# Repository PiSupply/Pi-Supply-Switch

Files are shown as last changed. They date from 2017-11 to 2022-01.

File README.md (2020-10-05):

pisupply-switch-banner
# Pi-Supply-Switch
[Pi Supply Switch On/Off Switch](https://www.pi-supply.com/product/pi-supply-raspberry-pi-power-switch/) for Raspberry Pi

**Remember to install the code before connecting the switch to the Pi.**

## Installation
1. Login via SSH or via the console.
2. Run the following command and Pi Switch will be setup and installed:
```bash
curl -sSL https://pisupp.ly/piswitchcode | sudo bash
```
For OctoPrint run the following:
```bash
curl -sSL https://pisupp.ly/piswitchoctoprint | bash
```

With this new script any standard pin can be chosen to provide the function previously covered by pins 7 and 8.
Within softshut.py you can change the assignment which by default is

```python
PinSeven = 7
PinEight = 11
```

This means that pin 7 coming from the Pi Switch goes to pin 7 on the Raspberry Pi and that pin 8 from the Pi Switch goes to pin 11 on the Raspberry Pi.

```
PiSwitch 7 <---> RPi 7
PiSwitch 8 <---> RPi 11
```

Remember that the notation used is the physical notation only.

**Note that the file to be changed once the installation has been carried out is located under /opt/piswitch/softshut.py and will need to be edited as root**
```bash
sudo nano /opt/piswitch/softshut.py
```

## Usage

* Press the On button to power on the Raspberry Pi.
* Press the Off button to remove power to the Raspberry Pi. This is not a graceful shutdown!
* Press briefly the Soft button to gracefully shutdown the operating system. After 2 minutes the power is also cut off.
* Press the Soft button and keep pressed for a reboot.

# FAQ
## My Pi switches off before fully booting
To avoid this condition always use the Pi Switch in conjunction with the script above. Neither the switch nor the script will work on their own and will result in the powering off of the Raspberry Pi shortly after booting. As previously pointed out you need to install the code before connecting the switch. To remove the switch run the uninstall.sh script before returning to powering the Raspberry Pi only with a traditional PSU.
Should you not have been able to run the uninstall.sh in order to be able to access your OS without it prematurely powering off you can use the following workaround.
Use the jumper cable provided with the switch and connect pin 7 on the Raspberry Pi to pin 9 (GND) and boot normally. This will trick the script into behaving as if the Pi Switch was connected. At this point you can run the uninstall.sh, power off the system and unplug the jumper cable.

## Where can I find an assembly guide?
A [text guide](https://learn.pi-supply.com/make/pi-supply-switch-assembly-instructions/) can be found on our website alternative you can also find a [steb by step video](https://www.youtube.com/watch?v=bHj_pMD7oLI&feature=youtu.be).

## I am still running Wheezy where can I find compatible code?
The [original code for the Pi Switch](https://learn.pi-supply.com/pi-supply-switch-v1-1-code-examples/) can be found on our website.

## Raspbian shows under-voltage warnings
The problem can be solved by using shorter, thicker USB cables. With Pi Switch we are now shipping 30cm 22AWG USB cables which solve the problem entirely.

## How do I know if the service is running properly?
Run the following command
```bash
systemctl status piswitch.service
```
which should return something like
```
● piswitch.service - Starts softshut for Pi Switch
   Loaded: loaded (/etc/systemd/system/piswitch.service; enabled)
   Active: active (running) since Thu 2017-06-29 09:56:13 UTC; 6min ago
 Main PID: 427 (python)
   CGroup: /system.slice/piswitch.service
           └─427 python /opt/piswitch/softshut.py

```

## Open Source Hardware

We are proud to say that the Pi Supply Switch is certified by the [Open Source Hardware Association](https://certification.oshwa.org/uk000019.html) with UID number UK000019. Our certification mark is below:

OSHW_mark_UK000019

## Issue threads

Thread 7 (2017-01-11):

Unexpected shutdown without pressing the button

coconut147, 2017-01-11:
I recognized some unexpected shutdowns with my PiSupply Board.

First I thought it is an hardware issue and started to measure with an oscilloscope but everything looked fine.
I recognized that touching mass the raspberry _can_ invoke the shutdown.

It seems that spikes will produce rising edges on the GPIO.

I already created a proof of concept on my fork at the branch "coconut147_RetroPi"

https://github.com/coconut147/Pi-Supply-Switch/tree/coconut147_RetroPi

If you have a look at commit
https://github.com/coconut147/Pi-Supply-Switch/commit/e24678bb18e51f845d3375cab7b9fa1b2fbed239

you'll find my approach I'm testing right now.

francesco-vannini, 2017-01-11:
Thanks Freddy, that's interesting although a bit disappointing :(
I'll test tomorrow myself and incorporate your changes.

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

--
Francesco Vannini

Website http://garagetech.tips
LinkedIn https://uk.linkedin.com/in/garagetechlinkedin
Youtube https://www.youtube.com/user/Happylotube
Twitter @GarageTechTweet
Facebook https://www.facebook.com/GarageTechBook/
<https://m.facebook.com/GarageTechBook/>
Google+ https://plus.google.com/+FrancescoVannini

shawaj, 2017-01-11:
@coconut147 what do you mean by "touching mass"?

coconut147, 2017-01-11:
I meant touching some point at the board that has connection to ground.

If you have a look at the original example code snippet, there is a debouncing  setting. I assume that this is the reason why it wasn't discovered earlier...
'''
gpio.add_event_detect(7, gpio.RISING, callback=shutdown, bouncetime=200) # Set up an interrupt to look for button presses
 '''

coconut147, 2017-01-11:
Just to clarify:

"Unexpected shutdown": The soft off functionality of the script is invoked, it's not a hard power cut

shawaj, 2017-01-11:
Aha good spot! Thanks

shawaj, 2017-01-11:
If you add deboince back in does it fix the problems?

coconut147, 2017-01-12:
I did not test the debounce setting. But my code is basically doing the same. When an edge is detected, it waits for 100ms. If the button is still pressed, the shutdown is invoked, otherwise ignored.

shawaj, 2017-01-12:
The debounce setting would be a "cleaner" way to do it though surely?

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

coconut147, 2017-01-12:
Please have a look at https://sourceforge.net/p/raspberry-gpio-python/wiki/Inputs/

I think the function "add_event_detect" - that has the debounce parameter - is supposed to be used in games or programs where you don't want to have a blocking call to wait for a "user input".

In the case of the Pi-Supply-Switch we want to have a service that does not use much CPU time. So wait_for_edge() is the way to go in my opinion. The function will suspend the running process until there is an interrupt on the GPIO.

If an edge is detected the program can sleep (thread suspended again) for 100 ms. Afterwards we'll check the actual state if the GPIO. If the button is still pressed we have a confirmed pressed button and can do the shutdown - if the button has been released before we might have seen a spike. In this case we shouldn't do anything and wait for another interrupt of the GPIO.

shawaj, 2017-01-12:
Great explanation and you're right that sounds like the best way

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

coconut147, 2017-01-15:
I created a PR that includes the fix.

francesco-vannini, 2017-01-15:
I understand your points but I believe we should use
"add_event_detect" instead and use a callback function:

def shutdown():
    GPIO.output(PinEight,0)
    call('poweroff', shell=False)

GPIO.add_event_detect(PinSeven, GPIO.RISING, callback=shutdown,
bouncetime=100)

it is more readable and I feel more appropriate, also it doesn't require
the additional time library.
Thoughts?

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

--
Francesco Vannini

<https://twitter.com/GarageTechTweet>
<https://www.youtube.com/user/Happylotube>
<https://uk.linkedin.com/in/garagetechlinkedin>
<https://www.facebook.com/GarageTechBook/>
<https://plus.google.com/+FrancescoVannini>
<http://garagetech.tips/?feed=rss2>  <http://blog.happylot.net/>

coconut147, 2017-01-15:
What will you do to halt execution after registering the callback?
add_event_detect is a non blocking call, so the script needs to do something afterwards.

You might want to halt the execution forever, perhaps with a ```while(True)``` loop - but that eats up 100% CPU load on  a rPI 1 with basically doing nothing.

If you want to tell the application to suspend - you might want to use ```sleep()```
But that also implies you'll have to import the time library...

francesco-vannini, 2017-01-15:
Yes you are right, I was just about to email you again.
At the moment I can't see any other way. I'll test your code and get on
with the PR.

Thanks

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

--
Francesco Vannini

<https://twitter.com/GarageTechTweet>
<https://www.youtube.com/user/Happylotube>
<https://uk.linkedin.com/in/garagetechlinkedin>
<https://www.facebook.com/GarageTechBook/>
<https://plus.google.com/+FrancescoVannini>
<http://garagetech.tips/?feed=rss2>  <http://blog.happylot.net/>

francesco-vannini, 2017-01-15:
Solved in commit #8

Closed 2017-01-15.

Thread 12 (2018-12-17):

Shutdown after a few minutes

martinjungkunz, 2018-12-17:
Hi there,

I have some problem with my Py-Supply On/Off Switch. On and Off work perfectly fine but the soft shutdown does not. That's not much of a problem since my main goal is to cut the power off.

Secondly, the Pi shuts down after a few minutes when used with the Pi-Supply. It's a hard shutdown. I installed the scripts from Github so I think the problem is with the hardware. Have you ever heard of the board acting like that?
Thank you in advance, best
Martin

martinjungkunz, 2018-12-17:
Yes I did and I got the message posted in the your link

shawaj, 2018-12-17:
It sounds like you didn't connect the flying GPIO cable between the switch and the Pi?

martinjungkunz, 2018-12-18:
Actually i did connect it. If I don't, the Pi aborts the boot after a few seconds. In my case it works fine for about 1 to 3 minutes and then suddenly shuts down.

shawaj, 2018-12-18:
It is likely you don't have the software correctly running then or you haven't connected the cable to the correct pin.

That's really the only two things that can cause the issue you're seeing.

martinjungkunz, 2018-12-18:
Hahaha... and just after I wrote my answer I re-read the readme and realized that 8 goes to 11... will try that later

shawaj, 2018-12-18:
Awesome, let us know how you get on

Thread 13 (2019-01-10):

Start up using pins ( from another pi)

bortek, 2019-01-10:
I understand that this can be used to cut the power off but is there a way to start up pi using Pins and not a button? My intention is to use another pay to control "main" pi both cutting power and starting it up (cold reset).

tvoverbeek, 2019-01-10:
Since SW1 can be used to both shut down (and power off) the Pi (long press) and start it up (short press) you should be able to use the unpopulated header J5 which is in parallel to SW1. Provide a short 3.3V pulse to start it up and a long pulse for shutting it down. For timing see the SW1 settings in the GUI/CLI. Check which pin of J5 has the constant 3.3V and connect the other one to an GPIO output of the other Pi.

bortek, 2019-01-18:
Hmm that should probably work. Let me get the board first and test it.

Do I need any resistors between GPIO and pins or can I connect them directly ?

tvoverbeek, 2019-01-18:
The PiJuice already has a 3k9 resistor between the J5 pin and the sw input.
Hence you should be able to connect the GPIO output from the other pi to the J5 pin directly.

bortek, 2019-01-18:
I was planning to use PiSwitch only, without using PiJuice. Is it possible? And if yes then how do I do about 3.9 resistor?

tvoverbeek, 2019-01-18:
@bortek That is something different from what you wrote originally.
I understood that you wanted to use the main Pi + Pijuice combination controlled by a second RPi.
Do you mean main Pi + PiSwitch controlled from a second RPi?
I do not know the PiSwitch details, but after a quick look at the schematic and docs I do not think its possible.

Closed 2019-01-20.

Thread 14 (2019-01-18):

Start and Stop work.  Shutdown does not

matt-benett, 2019-01-18:
Hello, I have 1.1 on a RPi 3 B+.  Latest version of Retropi.  All updated.

Start works - when on Pi Supply LED is on.
Hard Stop works - when off Pi Supply LED is off.

My issues is:
Soft shutdown does nothing on the Pi or the screen output.  The Pi Supply it turns the LED off/on when I press it.  It does not even kill power after 2 minutes.

piswitch service is running.

I am plugged into Pin 7 and 11.

Any ideas please?
thanks

tvoverbeek, 2019-01-19:
@matt-benett Are you using any GPIO based controllers with Retropie?
Looking at https://github.com/RetroPie/RetroPie-Setup/wiki/GPIO-Modules
It seems some of those modules use pins 7 and 11 which will interfere with the piswitch service.

matt-benett, 2019-01-19:
> @matt-benett Are you using any GPIO based controllers with Retropie?
> Looking at https://github.com/RetroPie/RetroPie-Setup/wiki/GPIO-Modules
> It seems some of those modules use pins 7 and 11 which will interfere with the piswitch service.

no, using USB controller

tvoverbeek, 2019-01-19:
@matt-benett Do you have wiringpi installed?
If not install it with `sudo apt-get install wiringpi`.
Then please provide the output of `gpio readall`
The interesting items are the ones for physical pins 7 and 11

matt-benett, 2019-01-19:
Output

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

Image to preserve formatting

tvoverbeek, 2019-01-20:
RPi GPIO pins 7 (BCM 4) and 11 (BCM17) have the correct state and level.
you wrote earlier the piswitch service is running.
What is the output from `systemctl status piswitch.service`?
Double check the connections from Pi-Switch pins 7 and 8 to RPI GPIO pins 7 and 11 respectively.
See the assembly guide (I guess you did this already).
To get a soft shutdown the press the soft button less than 2 seconds (again, I guess you know this).
Note the warning in the assembly guide about Pi3B and 3B+.

matt-benett, 2019-01-21:
ta.

I am looking at the new and old pin images, and they look the same to me.  Am I missing something?

https://i0.wp.com/learn.pi-supply.com/wp-content/uploads/2013/06/Pins-New-Soft.jpg?w=1000&ssl=1

https://i2.wp.com/learn.pi-supply.com/wp-content/uploads/2018/12/20181218_164817.jpg?w=1000&ssl=1

I will check output of `systemctl status piswitch.service` tonight, but I recall it looking all ok.

shawaj, 2019-01-22:
The options as shown in the two pictures here are pins 2 and 6 or pins 7 and 11 - https://learn.pi-supply.com/pi-supply-switch-v1-1-assembly-instructions/

But with the Pin 7 / 11 you need the software running on the pi for it to work correctly

LDDill, 2020-01-31:
Hi I am having the same issue as @matt-benett. The ON and Off buttons work but not the Soft Off button. Show below is what I get when I run "systemctl status piswitch.service". Any suggestions?

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

Thanks

Velocity2018, 2020-02-01:
Did you remember to edit the Python script to change the pin numbers?

LDDill, 2020-02-01:
@Velocity2018 I opened the code to edit it, but it appeared to already be correct.

  GNU nano 2.7.4                            File: /opt/piswitch/softshut.py                               
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

Is there something I need to edit in this file?

Thanks!

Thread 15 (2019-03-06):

Install trying to pull old file version?

Turnwise, 2019-03-06:
Using the command curl -sSL https://pisupp.ly/piswitchcode | sudo bash the install appears to be trying to get the older version of the piswitch code  - deb9u2, when the most recent is d53ff4c I think?

The error is:  Failed to fetch http://mirrordirector.raspbian.org/raspbian/pool/main/g/git/git_2.11.0-3+deb9u2_armhf.deb  404  Not Found [IP: 93.93.128.193 80]

francesco-vannini, 2019-03-07:
Hi @Turnwise , AFAICT the install script uses

`git clone https://github.com/PiSupply/Pi-Supply-Switch.git`

and the URL [https://pisupp.ly/piswitchcode](url) retrives the right version of install.

Could you use a browser and verify that the version of install on the master branch is the same you get?

Even just by running `curl -sSL https://pisupp.ly/piswitchcode`

you should get:

#!/usr/bin/env bash

#Check if script is being run as root
if [ "$(id -u)" != "0" ]; then
   echo "This script must be run as root" 1>&2
   exit 1
fi

if [ ! $? = 0 ]; then
   exit 1
else
   apt-get install -y git whiptail #Installs packages which might be missing

   PiSupplySwitchDir="Pi-Supply-Switch"
   if [ -d "$PiSupplySwitchDir" ]; then
    whiptail --title "Installation aborted" --msgbox "$PiSupplySwitchDir already exists, please remove it and restart the installation" 8 78
    exit
   else
    git clone https://github.com/PiSupply/Pi-Supply-Switch.git
   fi

   mkdir /opt/piswitch

   cp $PiSupplySwitchDir/softshut.py /opt/piswitch
   if [ ! -f /opt/piswitch/softshut.py ]; then
     whiptail --title "Installation aborted" --msgbox "There was a problem writing the softshut.py file" 8 78
    exit
   fi
   cp $PiSupplySwitchDir/piswitch.service /etc/systemd/system
   if [ ! -f /etc/systemd/system/piswitch.service ]; then
    whiptail --title "Installation aborted" --msgbox "There was a problem writing the piswitch.service file" 8 78
    exit
   fi

   systemctl enable /etc/systemd/system/piswitch.service
   whiptail --title "Installation complete" --msgbox "Pi Switch installation complete. The system will power off." 8 78
   poweroff
fi

shawaj, 2019-03-08:
The mirror director URL is something to do with the pi repos.

Perhaps try sudo apt-get update and sudo apt-get upgrade too

Turnwise, 2019-03-09:
Thanks both :)

I'm a bit of a beginner with Pi, and bash scripts etc, so bare with me please - in my day job I'm a PL-SQL developer, but we have a whole department to deal this the more tech side of setting stuff up, etc...

francesco-vannini -  Yes, I tried that and compared the install script that took me to against the code I can see just clicking on the install.sh code.

All seems good until the script reaches the clone bit, then it can't find the version it's looking for - hence the 404 Not Found at that point?  Thanks :)

shawaj - "The mirror director URL is something to do with the pi repos" - that sounds possible - I will try your suggestions - I did think the whiptail bit probably did that, but not sure...   I'll come back on this when I get chance to try it, Thanks :)

For anyone interested - or who cares, here's the putty messages from running curl -sSL https://pisupp.ly/piswitchcode | sudo bash

pi@raspberrypi:~ $ curl -sSL https://pisupp.ly/piswitchcode | sudo bash
Reading package lists... Done
Building dependency tree
Reading state information... Done
whiptail is already the newest version (0.52.19-1).
Suggested packages:
  git-daemon-run | git-daemon-sysvinit git-doc git-el git-email git-gui gitk
  gitweb git-arch git-cvs git-mediawiki git-svn
The following packages will be upgraded:
  git
1 upgraded, 0 newly installed, 0 to remove and 119 not upgraded.
Need to get 3,380 kB of archives.
After this operation, 0 B of additional disk space will be used.
Err:1 http://mirrordirector.raspbian.org/raspbian stretch/main armhf git armhf 1:2.11.0-3+deb9u2
  404  Not Found [IP: 93.93.128.193 80]
E: Failed to fetch http://mirrordirector.raspbian.org/raspbian/pool/main/g/git/git_2.11.0-3+deb9u2_armhf.deb  404  Not Found [IP: 93.93.128.193 80]
E: Unable to fetch some archives, maybe run apt-get update or try with --fix-missing?
Cloning into 'Pi-Supply-Switch'...
cp: cannot stat 'Pi-Supply-Switch/softshut.py': No such file or directory
pi@raspberrypi:~ $

tvoverbeek, 2019-03-09:
The `apt-get install -y git whiptail` command at the beginning of the install script fails.
Probably because your `/etc/apt/sources.list` is out of date. mirrordirector.raspbian.org is not used any more.
Try to replace /etc/apt/sources.list with the following:
```
deb http://raspbian.raspberrypi.org/raspbian/ stretch main contrib non-free rpi
# Uncomment line below then 'apt-get update' to enable 'apt-get source'
#deb-src http://raspbian.raspberrypi.org/raspbian/ stretch main contrib non-free rpi
```
You need to edit /etc/apt/sources.list as root (using sudo).
Then run `sudo apt-get update` and `sudo apt-get dist-upgrade` to be sure you are up-to-date.
Then try the install again.

francesco-vannini, 2019-03-10:
Out of curiosity @Turnwise how did you download your Raspbian version? is this a new installation or you are adding the Pi Supply Switch to an existing project which you had been sitting there for a while?

Turnwise, 2019-03-10:
Not sure exact date - but probably around a year or so ago - the on/off switch is to attach to my Pi that is running BrewPi for me (to control temperature in a fermentation cupboard). When it's running, it's out in my shed, only connected to an arduino board that's controlling a relay board - but no screen, or keyboard connected - and I've never managed to connect to the Pi remotely to shut it down gracefully, and 9 times out of 10 it corrupts if I just switch it off, which isn't a disaster as I have a saved image I just drop back on the SD card and off we go again, but it is a bit of a pain, especially as we are out in the sticks and power cuts are more frequent than I'd like, and although usually intermittent, also tend to mean a re-install of the image....

francesco-vannini, 2019-03-11:
@Turnwise I'd follow @tvoverbeek advice and update the OS one way or another. Good luck and let us know how that goes.

Turnwise, 2019-03-17:
Thanks all :)

I've followed @tvoverbeek 's advice :)

I edited the sources list by navigating to it on Putty using the cd command and then edited using vi :
sudo vi sources.list
x to delete characters, i to insert - hit esc once finished inserting
the :wq to exit and save

I then ran the two updates recommended - both did a lot of work! However the dist-upgrade hit an error towards the end :

Preparing to unpack .../libapt-pkg5.0_1.4.9_armhf.deb ...
Unpacking libapt-pkg5.0:armhf (1.4.9) over (1.4.7) ...
dpkg-deb (subprocess): decompressing archive member: lzma error: compressed data is corrupt
dpkg-deb: error: subprocess <decompress> returned error exit status 2
dpkg: error processing archive /var/cache/apt/archives/libapt-pkg5.0_1.4.9_armhf.deb (--unpack):
 cannot copy extracted data for './usr/lib/arm-linux-gnueabihf/libapt-pkg.so.5.0.1' to '/usr/lib/arm-linux-gnueabihf/libapt-pkg.so.5.0.1.dpkg-new': unexpected end of file or stream
Errors were encountered while processing:
 /var/cache/apt/archives/libapt-pkg5.0_1.4.9_armhf.deb
E: Sub-process /usr/bin/dpkg returned an error code (1)

I ran the get update script again - it found nothing new to do, and then the upgrade again, but I got the same 'compressed data is corrupt'

The curl -sSL https://pisupp.ly/piswitchcode | sudo bash now appears to do nothing at all, the cursor just moves to a new line and no action appears to be taken.

Stepping through the individual items in the install script and running individually using sudo, I get as far as  cp $PiSupplySwitchDir/softshut.py /opt/piswitch  - and there I encounter : cp: cannot stat 'Pi-Supply-Switch/softshut.py': No such file or directory

My Mrs has run out of patience waiting for me to finish mucking about with this tonight, so I'm gonna shut it down and come back to it another night!!

Thanks all for your continued patience and support!!!

tvoverbeek, 2019-03-17:
@Turnwise Smells like you SD card is full, so adding anything new fails.
What does `df -h` say? Should show the space available on the different file systems.
I suspect / is full.

Turnwise, 2019-03-24:
Slightly over half full??

Filesystem      Size  Used Avail Use% Mounted on
/dev/root        29G  5.4G   22G  20% /
devtmpfs        458M     0  458M   0% /dev
tmpfs           462M     0  462M   0% /dev/shm
tmpfs           462M   12M  450M   3% /run
tmpfs           5.0M  4.0K  5.0M   1% /run/lock
tmpfs           462M     0  462M   0% /sys/fs/cgroup
/dev/mmcblk0p6   68M   21M   47M  31% /boot
tmpfs            93M     0   93M   0% /run/user/1000

tvoverbeek, 2019-03-25:
Ok, sd card is obviously not full. I seems you have installed Raspbian using NOOBS.
I guess somehow your os installation is messed up.
The only thing I can suggest is to start from scratch and install Raspbian directly using one of the images on the downloads page: https://www.raspberrypi.org/downloads/raspbian/
and then after the initial update/upgrade install the piswitch code.

Turnwise, 2019-03-25:
I've ordered a new SD, and have downloaded the Raspbian Stretch with desktop, without NOOBS. I'll then see how that works!  I'll be a week or so - the Pi was needed back for the BrewPi and is running with the old, but working image that has the BrewPi code and settings, but not the new switch.... fingers crossed there's no power cuts!

tvoverbeek, 2019-03-26:
@Turnwise Let us know how it goes.

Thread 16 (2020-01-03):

Use GPIO14 instead?

opjose, 2020-01-03:
I found this comment on another forum about GPIO.
---
"The one exception might be your pin 15, which looks like it must be GPIO14. However, this pin isn't a GPIO at startup - it's TxD, the serial transmit line - which may well be pulled high for normal TX operation. The TxD line won't become GPIO14 (and therefore go low) until you run your script that enables all 17 lines as GPIOs."

"As I learned from the forums, I use an LED hooked up to GPIO14 and mounted on my chassis to notify me when the pi has completely shut down (The LED is lit at boot and is turned off at shutdown after the files systems have been unmounted."
---

That being the case wouldn't it be better to use the GPIO14 (TxD) pin which appears to remain high during boot, then initialize it in the script as a GPIO line and immediately pull it high in the script?

That way if the user is NOT running the script but has connected the board to GPIO14, they will not experience shutdowns during or after the boot sequence...

Would that work?

Thanks.

shawaj, 2020-01-04:
Yes you can do this no problem.

See here https://github.com/PiSupply/Pi-Supply-Switch/blob/master/README.md#installation

Just change the line PinEight = 11 to PinEight = 8

Closed 2020-01-04.

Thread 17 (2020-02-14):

Softshut Not working

LDDill, 2020-02-14:
Hi I followed all of the instructions step-by-step. I am using a raspberry pi 3B+ running raspbian stretch. The ON and Off buttons work, but not the Softshut Off button. Shown below is what I get when I run "systemctl status piswitch.service". Any suggestions?

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

This is what my softshut.py file looks like.

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

Thanks!

shawaj, 2020-02-14:
Do you have the board hooked up to the Pi as per the guide linked below?

The options as shown in the two pictures here are pins 2 and 6 or pins 7 and 11 - https://learn.pi-supply.com/pi-supply-switch-v1-1-assembly-instructions/

But with the Pin 7 / 11 you need the software running on the pi for it to work correctly

LDDill, 2020-02-14:
Hi @shawaj thanks for reaching out. I have physically hooked up the power switch to my Pi in this order: USB to micro USB from power supply to power switch, USB to micro USB from power switch to Pi, Pin 7 on the power switch to Pin 7 on the Pi, and Pin 8 on the power switch to Pin 11 on the Pi. Because of the error I get when running "systemctl status piswitch.service", I believe my issue is with the software. The error is listed below:

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

Any suggestions?

Thanks!

LDDill, 2020-02-24:
I have found a solution to the error I was receiving, "RuntimeError: Error waiting for edge". There appears to be an issue in the RPi.GPIO directory when calling "GPIO.wait_for_edge(PinSeven, GPIO.RISING)". The code runs perfectly if that line is removed (as shown below).

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

shawaj, 2020-02-25:
@LDDill is this an error in our code? Or something you added?

LDDill, 2020-02-26:
@shawaj The original code had "GPIO.wait_for_edge(PinSeven, GPIO.RISING)" on line 17. However, the code would give an error when ran. After removing that line the code works correctly. With a press initiating shut down and a hold initiating reboot.

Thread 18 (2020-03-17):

Link for the text-guide not working

boschie, 2020-03-17:
Hello,

Is it possible to get all the related files, guides and programs in this repository? It would be more handy and links seems to disappear over time.

Hendrie

ChristopherRush, 2020-03-17:
@boschie Here you go - https://learn.pi-supply.com/make/pi-supply-switch-assembly-instructions/

boschie, 2020-03-17:
@ChristopherRush Thanks!

The link in the README.md is still wrong. Could this page be implemented in the wiki of this repository? Just to keep it all in one place...

ChristopherRush, 2020-03-17:
I'll update the link through Github but at the moment we will not use
Githib wiki since we don't want too many duplication of the same thing.

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

boschie, 2020-03-17:
Ok, thanks!

Closed 2020-03-17.

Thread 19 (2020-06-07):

There was a problem writing the softshut.py file Installation aborted

magellan-13016, 2020-06-07:
Hello,

I have an issue with the script installation.

I run the command

**_curl -sSL https://pisupp.ly/piswitchcode | sudo bash_**

and get the error

**_There was a problem writing the softshut.py file Installation aborted_**

I run this on my octoprint printer server on a raspberry Pi 3B +

Can someone help me please ?
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

shawaj, 2020-06-07:
@ChristopherRush do you have an octoprint setup you can test this with?

ryanteck, 2020-06-07:
Just quickly ran it, seems the issue is with the git clone as it fails due to recommending you don't run git as sudo which as the entire script is sudo'd then fails.

Here's the error log

```pi@octopi:~ $ curl -sSL https://pisupp.ly/piswitchcode | sudo bash
[sudo] password for pi:
Reading package lists... Done
Building dependency tree
Reading state information... Done
git is already the newest version (1:2.20.1-2+deb10u1).
whiptail is already the newest version (0.52.20-8).
whiptail set to manually installed.
The following package was automatically installed and is no longer required:
  libllvm8
Use 'apt autoremove' to remove it.
0 upgraded, 0 newly installed, 0 to remove and 0 not upgraded.
Please do not run git as root, your regular user account is enough :)

If you need to run git with root rights for some other application than
what comes preinstalled on this image you can remove this sanity check:

    sudo rm /root/bin/git

You might have to restart your login session after doing that.
cp: cannot stat 'Pi-Supply-Switch/softshut.py': No such file or directory```

Solution is likely modifying it to download the files directly maybe, or not running the entire script as root?

shawaj, 2020-06-07:
@ryanteck maybe just run the bite that need it as root is easiest?

magellan-13016, 2020-06-08:
To Aaron, Ryan and Christopher : Many thanks for your help. 3 persons to help me I would never expect that ! Now I'm sure one of you will find the solution. Many thanks to you !

ChristopherRush, 2020-06-08:
@ryanteck Did you test it on your OctoPrint? Script runs fine on Raspbian.

ryanteck, 2020-06-08:
Yeah that was on footprint.

On Mon, 8 Jun 2020, 10:17 Christopher Rush, <notifications@github.com>
wrote:

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

ChristopherRush, 2020-06-08:
@ryanteck @shawaj Aarons method seems to work. Run the script as normal user and add root to parts that require it.

magellan-13016, 2020-06-08:
Well... If I run the script as normal user, a message tell me it must be run with root privileges. The best way for me is a new script working for Octoprint.

ChristopherRush, 2020-06-08:
@magellan-13016 Try the following `curl -sSL https://pisupp.ly/piswitchoctoprint | bash`

magellan-13016, 2020-06-08:
Dear team, you're simply the best !

Install is now complete. I suggest you to add this script on the main page of Pi Supply Switch so evey people using Octoprint can install it without any issue.

Many many many thanks to all of you.

David.
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

ivanolenichev, 2020-06-08:
Hi Aaron, @shawaj . Sorry for the off topic post. I can’t contact you by mail or other channels. Please write how you can be contacted?

ChristopherRush, 2020-06-08:
@magellan-13016 Super, I have added it to the main readme section for OctoPrint.

Closed 2020-06-08.

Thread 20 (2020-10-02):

Open source hardware certification

shawaj, 2020-10-02:
Pi Supply Switch certification
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
[OSHW_mark_UK000019.pdf](https://github.com/PiSupply/Pi-Supply-Switch/files/5320742/OSHW_mark_UK000019.pdf)

ChristopherRush, 2020-10-05:
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

ryanteck, 2020-10-05:
Can I just ask why we keep uploading images as issues rather than putting them in the repositories.

Shouldn't they be uploaded to the repo?

shawaj, 2020-10-06:
@ryanteck main idea was to keep the repos tidy and uncluttered and then just link to the images

Closed 2020-10-02.

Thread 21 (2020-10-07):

Softshut reboots after a while

JLGBJ, 2020-10-07:
I have a raspberry pi 3B+, it was running ok both ON and OFF buttons were working perfect. A couple of weeks ago the OFF button started to reboot itself after approximately 3 min., it does a soft shutdown and after 3 min. reboot the PI, when pressed as second time is does a soft shutdown and stays shutdown, could it be a corrupt file? ,  I’m running Octopi.

shawaj, 2020-10-07:
Just to check do you have the 2 pin cable connected between the pi and the switch? If so which pins are you using on the pi and the corresponding pin on the switch?

Can you also post the script you are using? Did you just use the default install method shown in the readme or something else?

Did you make any updates or changes to the software or octopi at all recently?

JLGBJ, 2020-10-12:
Hi @shawaj, thanks for replaying, yes I have the 2 pin cable connected as per the instructions:

PiSwitch 7 <---> RPi 7
PiSwitch 8 <---> RPi 11

The script is softshut.py and it was installed as per de readme file , this is what it looks like:

#!/usr/bin/env python
# Import the modules to send commands to the system and access GPIO pins
from subprocess import call
import RPi.GPIO as GPIO
from time import sleep
# Map pin seven and eight on the Pi Switch PCB to chosen pins on the Raspberry Pi header
# The PCB numbering is a legacy with the original design of the board
PinSeven = 7
PinEight = 11
GPIO.setmode(GPIO.BOARD) # Set pin numbering to board numbering
GPIO.setup(PinSeven, GPIO.IN) # Set up PinSeven as an input
GPIO.setup(PinEight, GPIO.OUT, initial=1) # Setup PinEight as output
while (GPIO.input(PinSeven) == False): # While button not pressed
 GPIO.wait_for_edge(PinSeven, GPIO.RISING) # Wait for a rising edge on PinSeven
 sleep(0.1); # Sleep 100ms to avoid triggering a shutdown when a spike occured
sleep(2); # Sleep 2s to distinguish a long press from a short press
if (GPIO.input(PinSeven) == False):
 GPIO.output(PinEight,0) # Bring down PinEight so that the capacitor can discharge and remove power to the Pi
 call('poweroff', shell=False) # Initiate OS Poweroff
else:
 call('reboot', shell=False) # Initiate OS Reboot

No changes were made to the software or octopi. I´m running Octoprint V.1.4.2 and
Octopi V.0.17.0

JLGBJ, 2020-10-12:
Hi @shawaj, thanks for replaying, yes I have the 2 pin cable connected as per the instructions:

PiSwitch 7 <---> RPi 7
PiSwitch 8 <---> RPi 11

The script is softshut.py and it was installed as per de readme file , this is what it looks like:

#!/usr/bin/env python
#Import the modules to send commands to the system and access GPIO pins
from subprocess import call
import RPi.GPIO as GPIO
from time import sleep
#Map pin seven and eight on the Pi Switch PCB to chosen pins on the Raspberry Pi header
#The PCB numbering is a legacy with the original design of the board
PinSeven = 7
PinEight = 11
GPIO.setmode(GPIO.BOARD) # Set pin numbering to board numbering
GPIO.setup(PinSeven, GPIO.IN) # Set up PinSeven as an input
GPIO.setup(PinEight, GPIO.OUT, initial=1) # Setup PinEight as output
while (GPIO.input(PinSeven) == False): # While button not pressed
 GPIO.wait_for_edge(PinSeven, GPIO.RISING) # Wait for a rising edge on PinSeven
 sleep(0.1); # Sleep 100ms to avoid triggering a shutdown when a spike occured
sleep(2); # Sleep 2s to distinguish a long press from a short press
if (GPIO.input(PinSeven) == False):
 GPIO.output(PinEight,0) # Bring down PinEight so that the capacitor can discharge and remove power to the Pi
 call('poweroff', shell=False) # Initiate OS Poweroff
else:
 call('reboot', shell=False) # Initiate OS Reboot

No changes were made to the software or octopi. I´m running Octoprint V.1.4.2 and Octopi V.0.17.0

Thanks

JLGBJ, 2020-10-18:
@shawaj  Any suggestions

Thanks

shawaj, 2020-10-18:
@JLGBJ when you run the script directly, do you get any error messages at all?

JLGBJ, 2020-10-18:
@shawaj Thanks for your replay, No I don’t get any error, I get this when I check the status:
pi@octopi:~ $ systemctl status piswitch.service
● piswitch.service - Starts softshut for Pi Switch
   Loaded: loaded (/etc/systemd/system/piswitch.service; enabled; vendor preset: enabled)
   Active: active (running) since Mon 2020-10-12 11:55:26 BST; 6 days ago
 Main PID: 301 (python)
    Tasks: 1 (limit: 2077)
   Memory: 5.2M
   CGroup: /system.slice/piswitch.service
           └─301 python /opt/piswitch/softshut.py

Oct 12 11:55:26 octopi systemd[1]: Started Starts softshut for Pi Switch.

Could it be the Pi Switch it self and not the software?

Thanks

JLGBJ, 2020-10-18:
how do you run it directly?

El dom., 18 oct. 2020 a las 15:09, Aaron Shaw (<notifications@github.com>)
escribió:

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

JLGBJ, 2020-10-19:
@shawaj , sorted, I changed the Pi-Switch for another unit I had and it is working perfectly. Do you have any suggestions as to what component could be faulty, to see if I can repaired it?. Thanks for your help

shawaj, 2020-10-19:
It could be the relay perhaps isn't switching correctly

shawaj, 2020-10-19:
@JLGBJ can you send me an email to sales@pi-supply.com - I think we might have some spare in the warehouse. I could send you one :-)

Closed 2020-10-19.

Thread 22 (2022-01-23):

power off after two minutes

naturenergy, 2022-01-23:
Hello!

I have an issue where the Pi (Arm 6 Model A rev2) using Dietpi 8.02 OS which I understand is based on Bullseye Debian.

Powers off after about 2 minutes (sudden off no gentle shutdown - so risk of card corruption).

I installed the code and switch as per instructions and it has worked fine previously on raspberry OS lite (headless)

Keen to use DietPi however, and like its functionality.

I used the default pins 7 and 11, and tried again changing to pins 11,15 (editing the script) same result. Also tried changing the power lead and have a good 2A supply which is ample for model A.

Ran the service status diagnostic (with switch attached) :-

● piswitch.service - Starts softshut for Pi Switch
     Loaded: loaded (/etc/systemd/system/piswitch.service; enabled; vendor preset: enabled)
     Active: failed (Result: exit-code) since Sun 2022-01-23 09:32:20 GMT; 3min 34s ago
    Process: 182 ExecStart=/opt/piswitch/softshut.py (code=exited, status=127)
   Main PID: 182 (code=exited, status=127)
        CPU: 33ms

Jan 23 09:32:19 RPi1PV systemd[1]: Started Starts softshut for Pi Switch.
Jan 23 09:32:20 RPi1PV softshut.py[182]: /usr/bin/env: ‘python’: No such file or directory
Jan 23 09:32:20 RPi1PV systemd[1]: piswitch.service: Main process exited, code=exited, status=127/n/a
Jan 23 09:32:20 RPi1PV systemd[1]: piswitch.service: Failed with result 'exit-code'.

Then I tested it without the switch and the OS remains stable and on for a long time.

Looking at above - perhaps python hasn't been installed correctly by default in Dietpi? Any ideas? Thanks!

tvoverbeek, 2022-01-23:
I have no experience with DietPi, but from your status output it is obvious that the 'python' command is not defined.
In a terminal window (with switch not attached) try to run the command `python` which will most likely fail.
I guess only python3 is installed. To check this, try to run the command `python3` in the terminal window.
If that works change the first line in softshut.py to `/usr/bin/env python3`.
If that does not work you will have to install python (preferably python3, since python2 is not maintained any more).

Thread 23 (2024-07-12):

Error: No module named 'RPi' - RPI shuts down after 30sec

silas-vj, 2024-07-12:
Hi there,

I hope I can get this issue fixed, because my system worked completely fine before but after a crash I had to do a fresh install on my RPI 3 B+ and now after I press the ON Button the RPI shuts down after approx. 30sec during boot, because the relay cuts off power. I cannot make the system boot normally.

I hooked it up to a second power supply, booted and entered "systemctl status piswitch.service" via ssh.

I am getting the following Response message (see also picture attached below):

● piswitch.service - Starts softshut for Pi Switch
    Loaded: loaded (/etc/systemd/system/piswitch.service; enabled; vendor preset: enabled)
   Active: failed (Result: exit-code) since Fri 2024-07-12 19:14:57 CEST; 38min ago
   Main PID: 616 (code=exited, status=1/FAILURE)

Jul 12 19:14:53 np-one systemd[1]: Started Starts softshut for Pi Switch.
Jul 12 19:14:57 np-one softshut.py[616]: Traceback (most recent call last):
Jul 12 19:14:57 np-one softshut.py[616]:   File "/opt/piswitch/softshut.py", line 5, in <module>
Jul 12 19:14:57 np-one softshut.py[616]:     import RPi.GPIO as GPIO
Jul 12 19:14:57 np-one softshut.py[616]: ModuleNotFoundError: No module named 'RPi'
Jul 12 19:14:57 np-one systemd[1]: piswitch.service: Main process exited, code=exited, status=1/FAILURE
Jul 12 19:14:57 np-one systemd[1]: piswitch.service: Failed with result 'exit-code'.

Thank You!

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

silas-vj, 2024-10-07:
Instructions explained in following volumio community thread:
[https://community.volumio.com/t/pi-supply-switch-v1-1-working-with-volumio-v2-246/6730](url)

Closed 2024-10-07.

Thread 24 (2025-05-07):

software does not install

mindstorm2099, 2025-05-07:
I am busy with making a NAS from my raspberry Pi 4 following the guide from https://wiki.omv-extras.org/doku.php?id=omv7:raspberry_pi_install.
But when i try the commabd: "curl -sSL https://pisupp.ly/piswitchcode | sudo bash"
i get the following error: "bash: line 1: error: command not found".
It doesn't matter if i try before installing openmediavault or after.
i know nothing about programming or stuff like that, so i need some help.

lbussy, 2025-05-07:
I am not the author, but maybe this will help.

The domain pisupp.ly (as well as pi-supply.com) is not there, so the short form of the URL is likewise unreachable.  MAYBE this is the right script:

https://github.com/PiSupply/Pi-Supply-Switch/blob/master/install.sh

So the replacement command would be:

```bash
curl -sSL https://raw.githubusercontent.com/PiSupply/Pi-Supply-Switch/refs/heads/master/install.sh | sudo bash
```

Good luck.

mindstorm2099, 2025-05-10:
Thank you.

With this command it works now. got a fully working NAS now.

P.S. i did needed to do a compleet reinstall, installing PiSupply after Openmediavault gives an error.
So a clean install of the OS then PiSupply and the OMV and it works.

Thank you again

Closed 2025-05-10.

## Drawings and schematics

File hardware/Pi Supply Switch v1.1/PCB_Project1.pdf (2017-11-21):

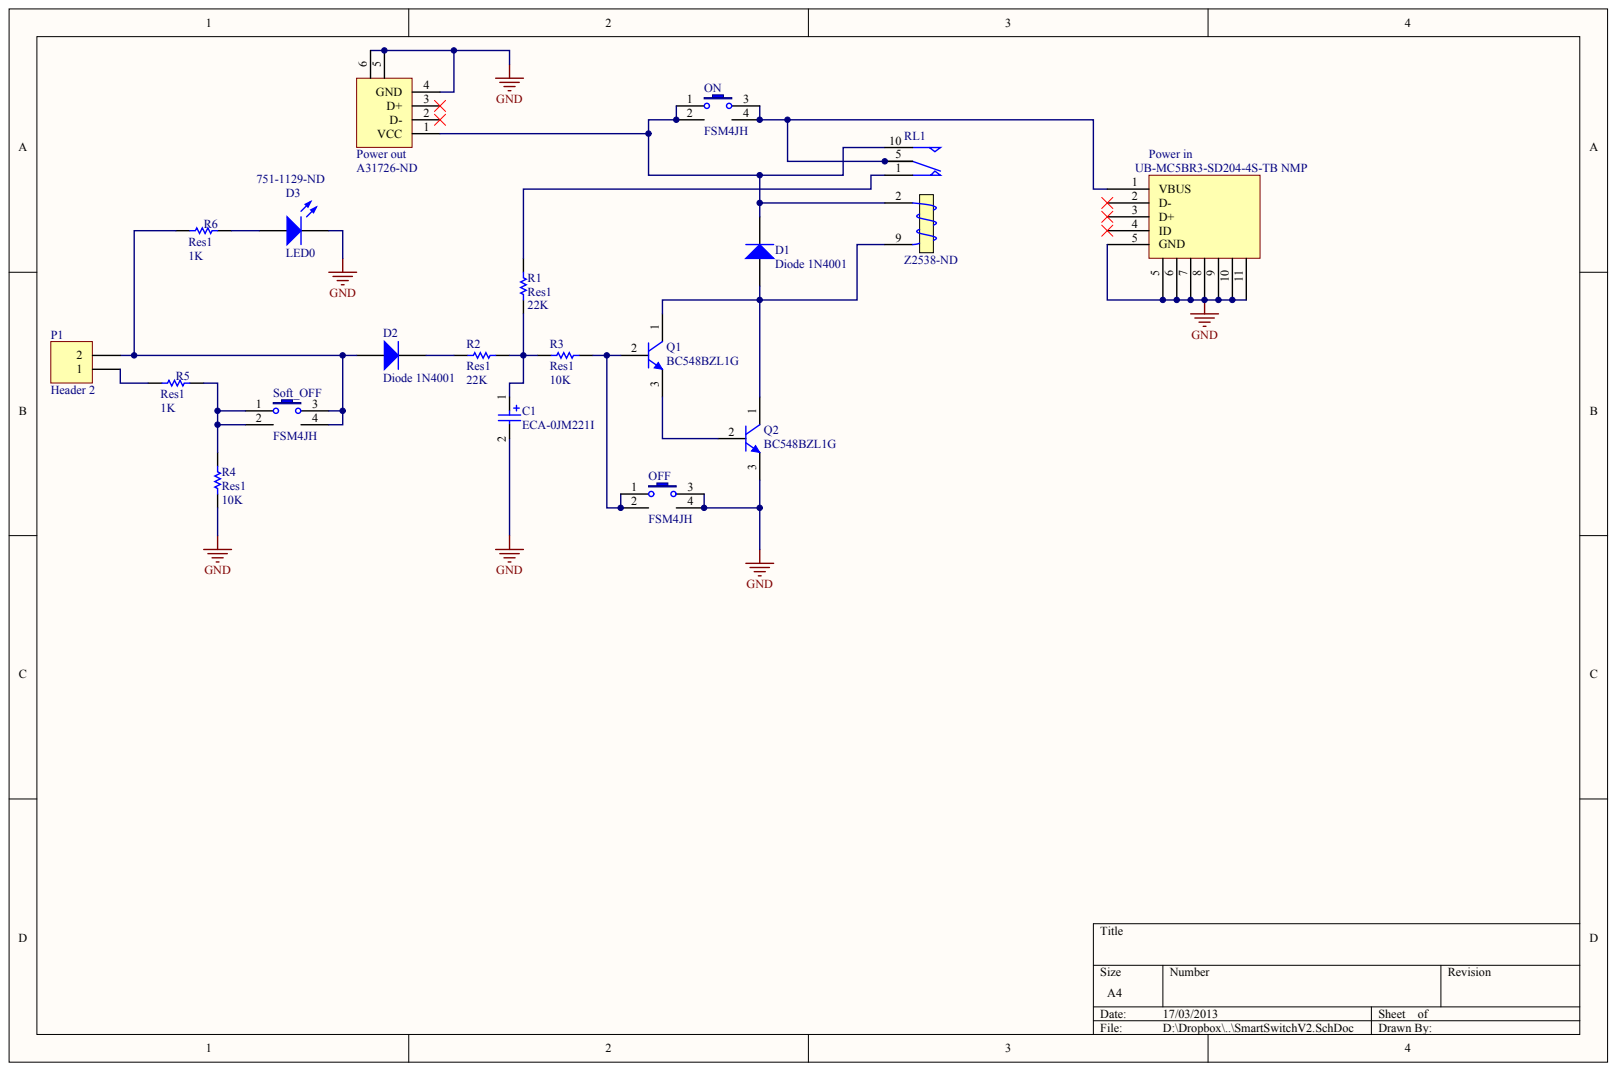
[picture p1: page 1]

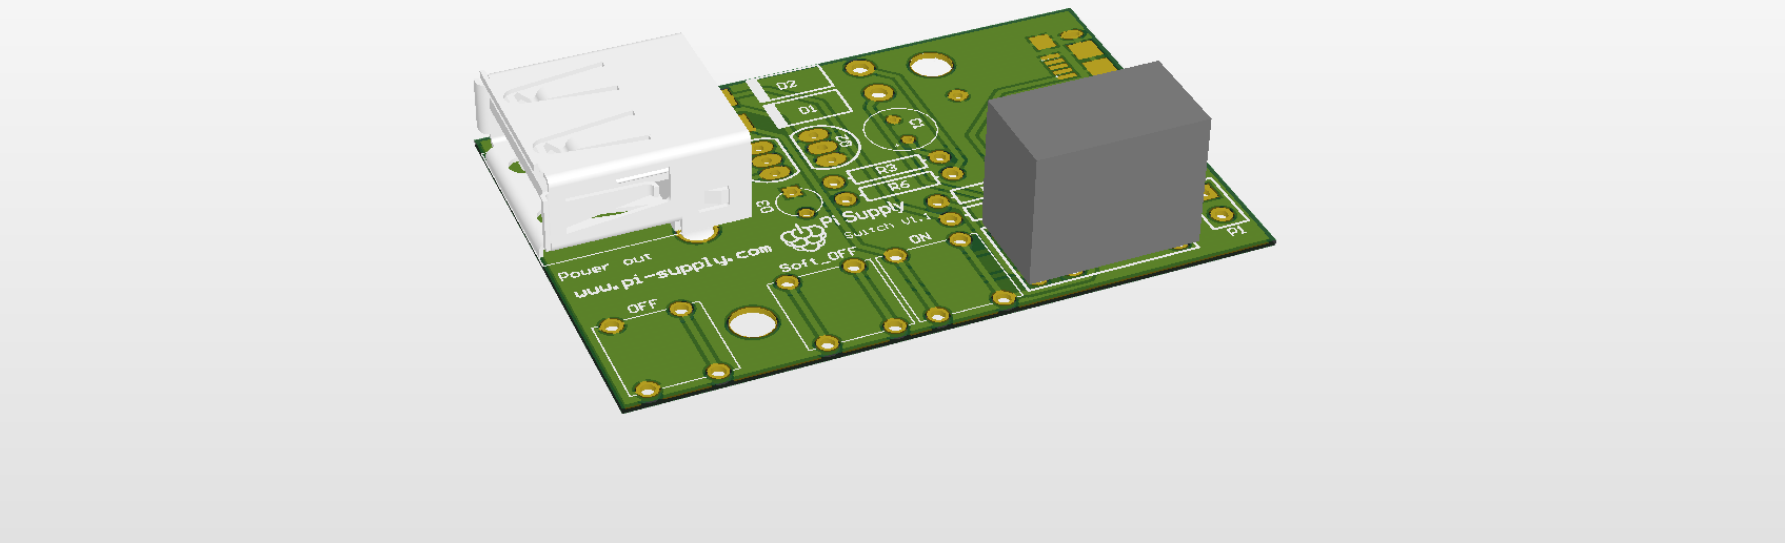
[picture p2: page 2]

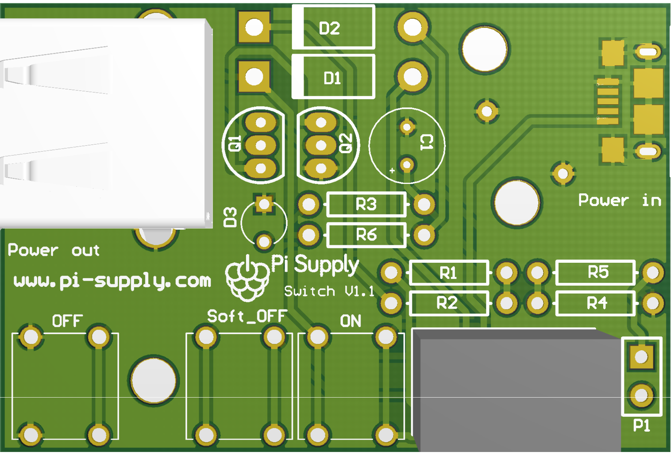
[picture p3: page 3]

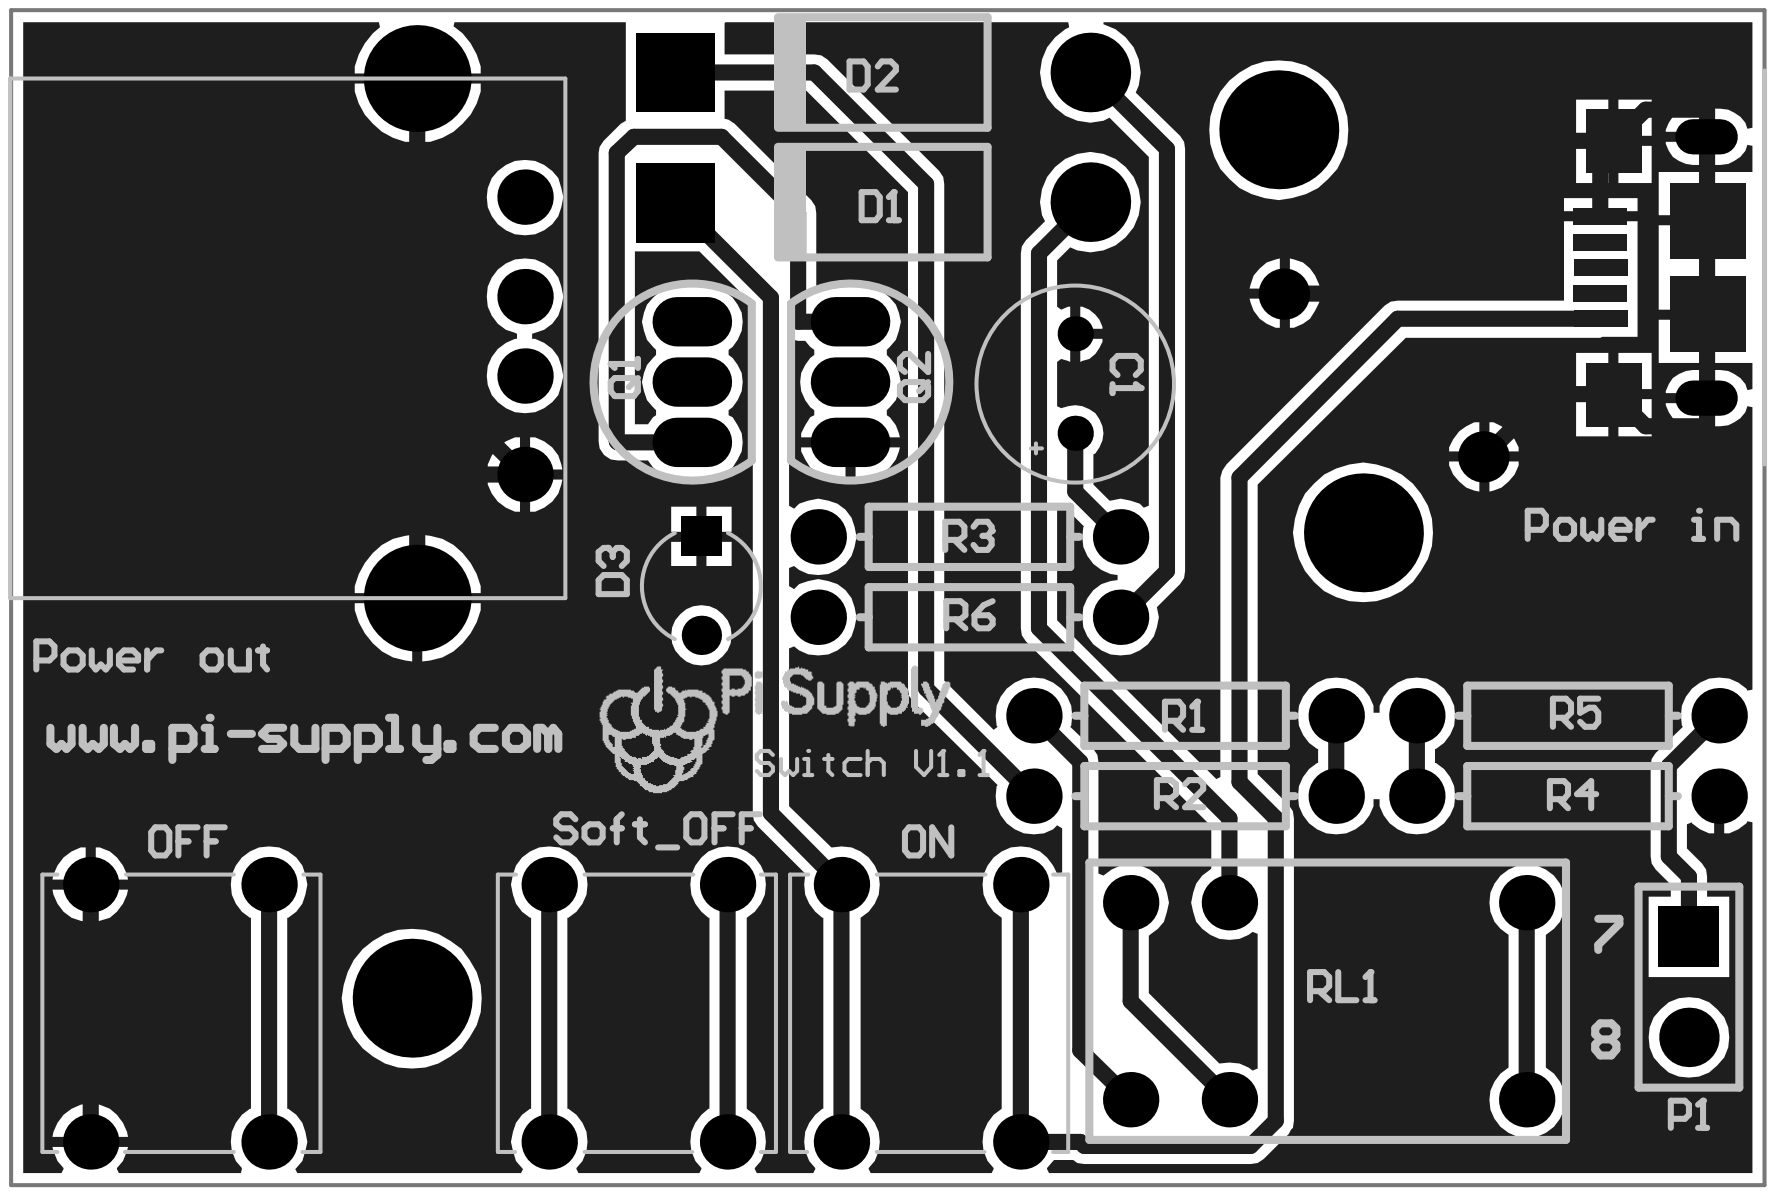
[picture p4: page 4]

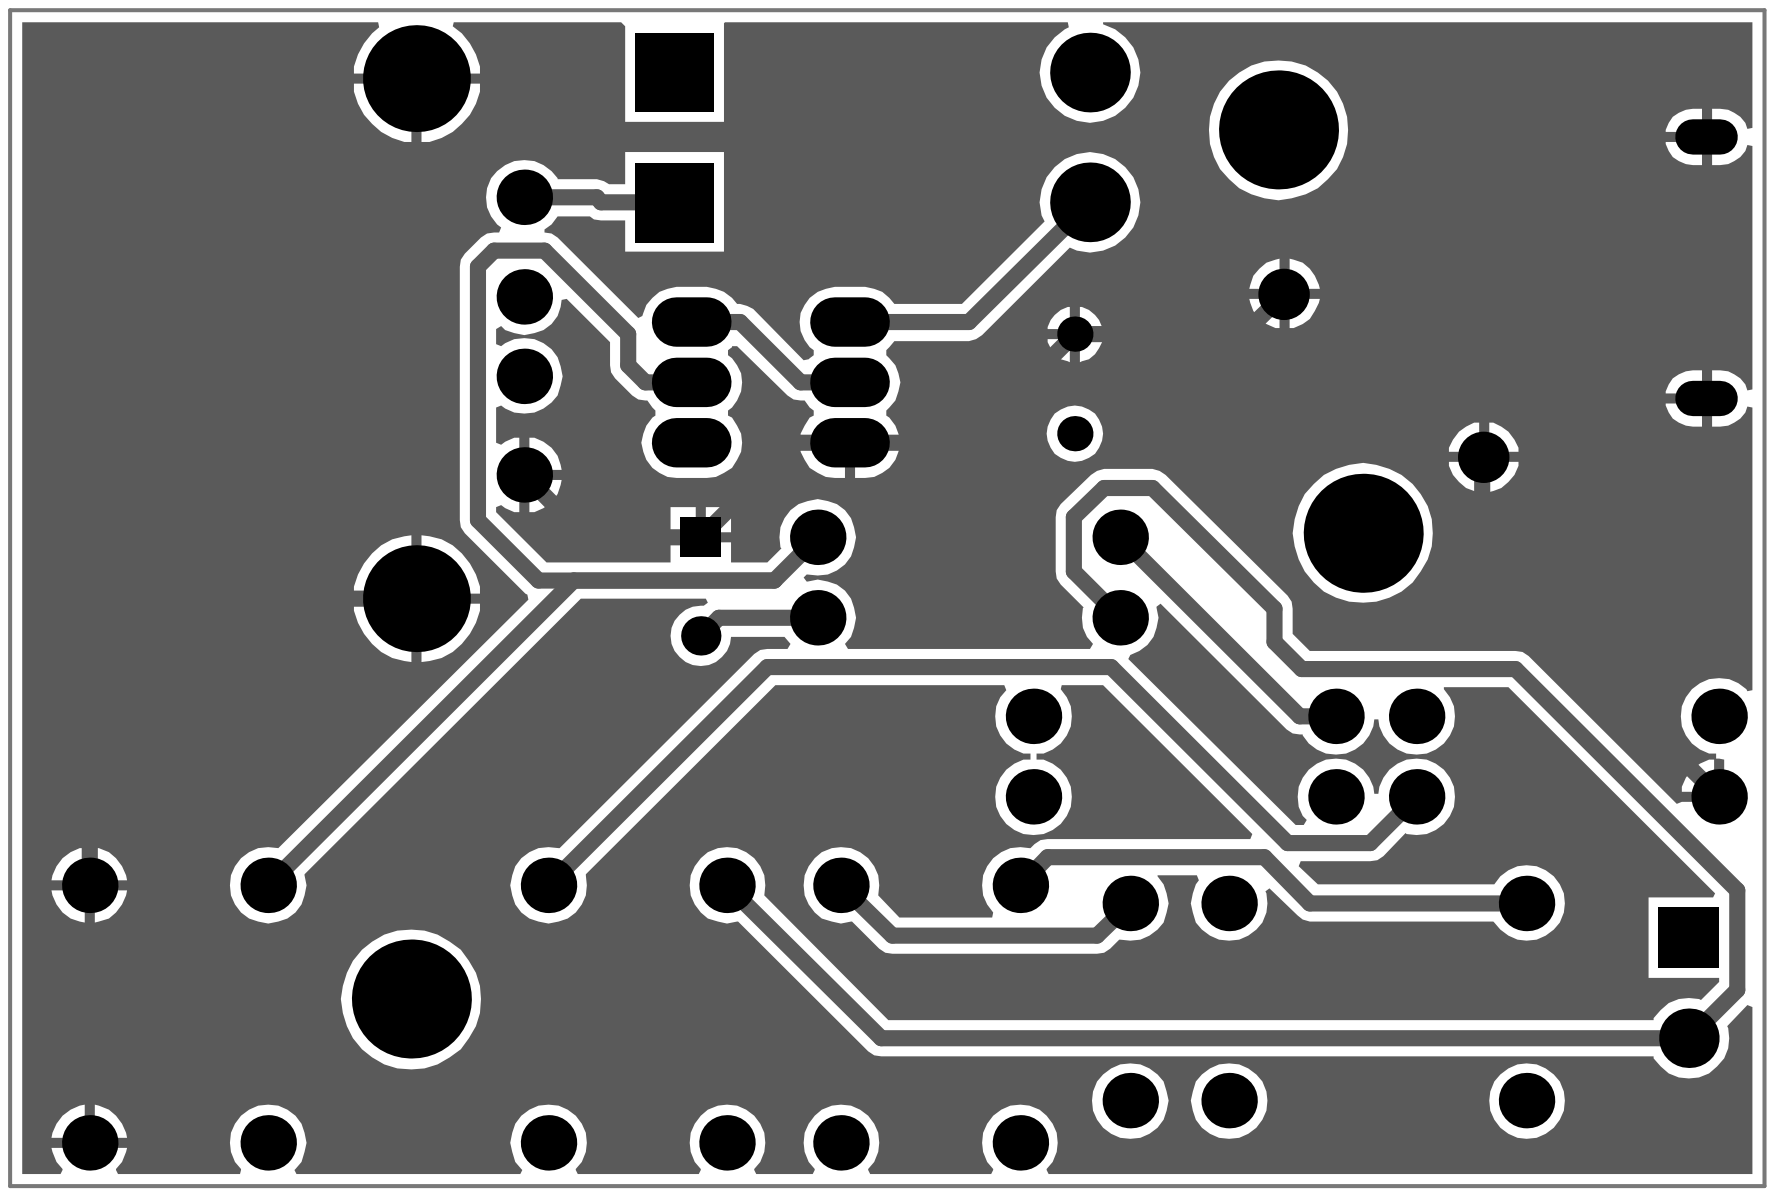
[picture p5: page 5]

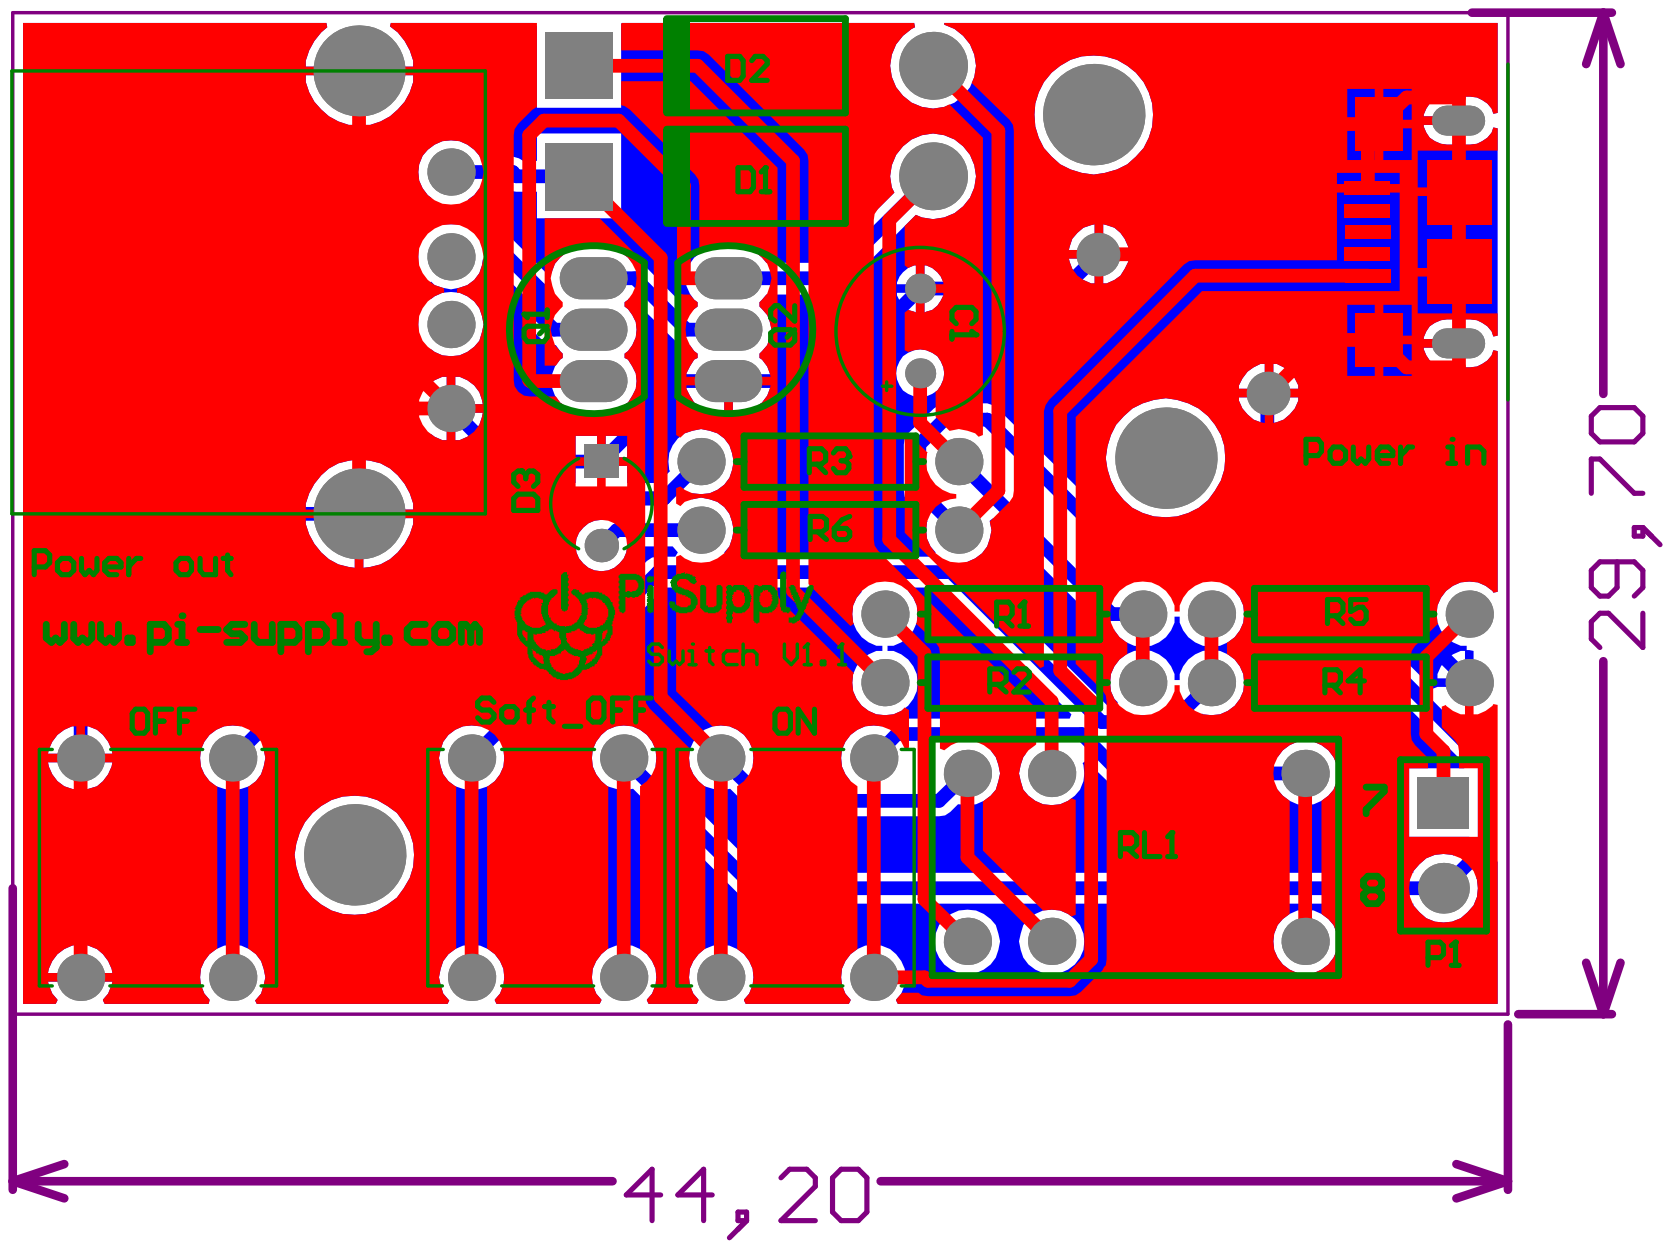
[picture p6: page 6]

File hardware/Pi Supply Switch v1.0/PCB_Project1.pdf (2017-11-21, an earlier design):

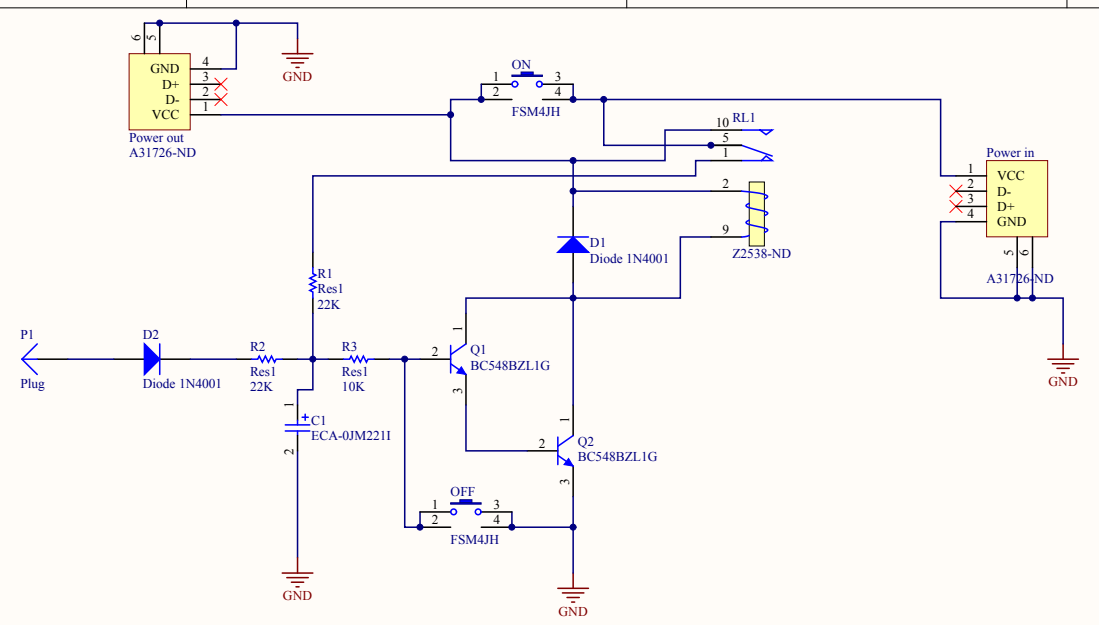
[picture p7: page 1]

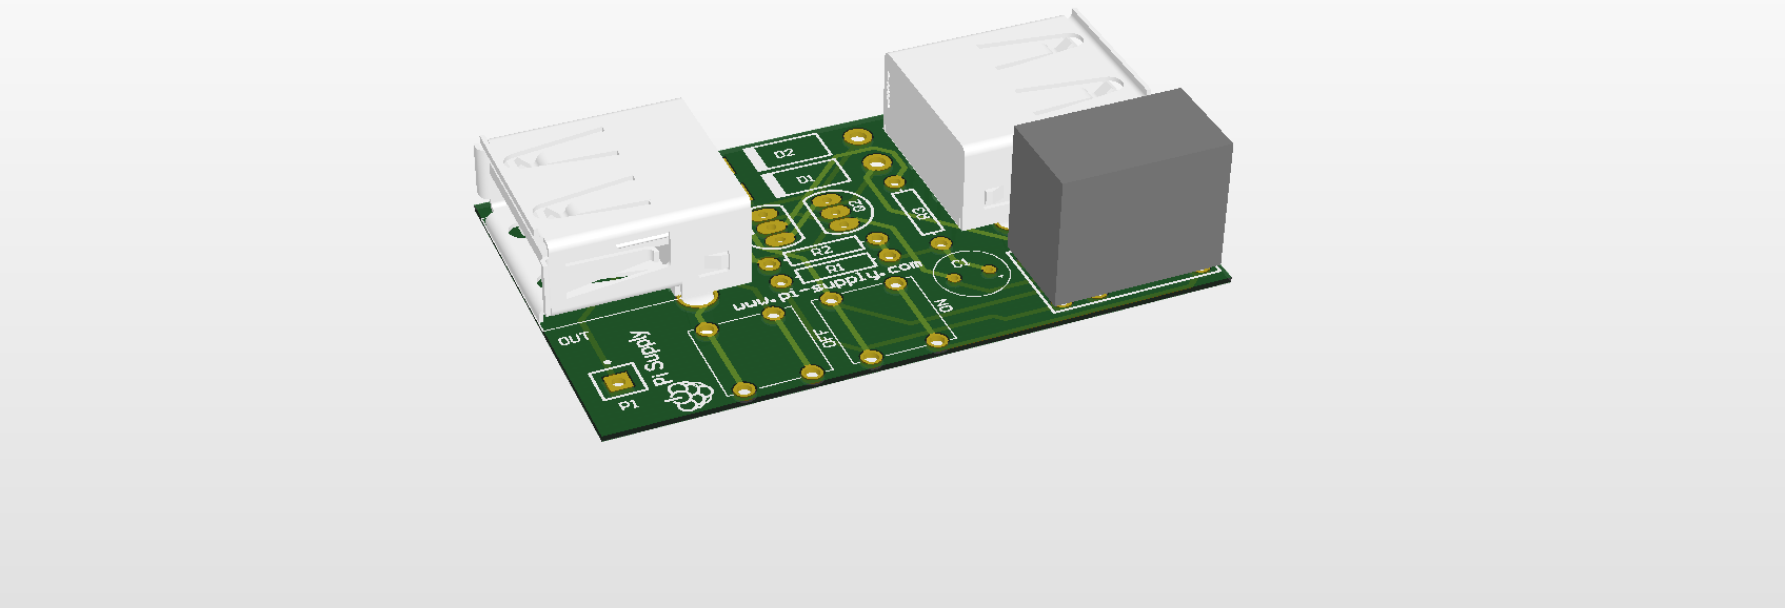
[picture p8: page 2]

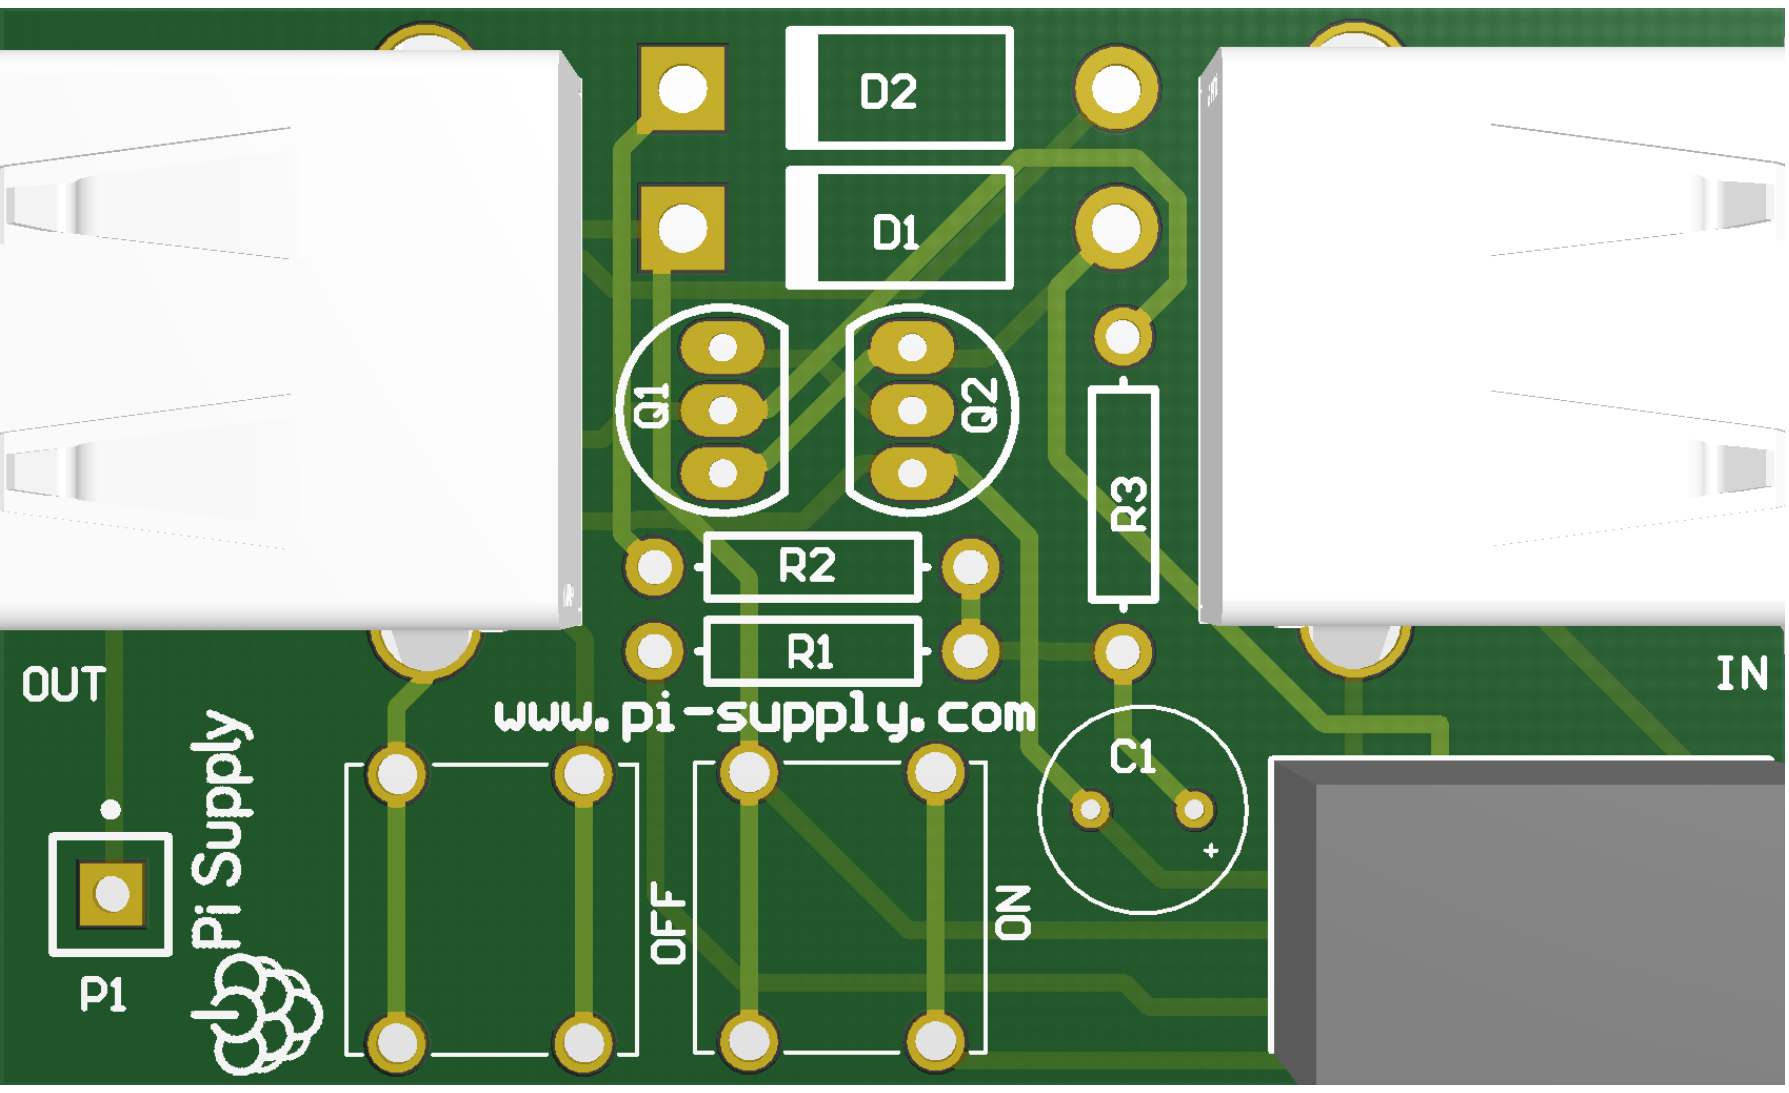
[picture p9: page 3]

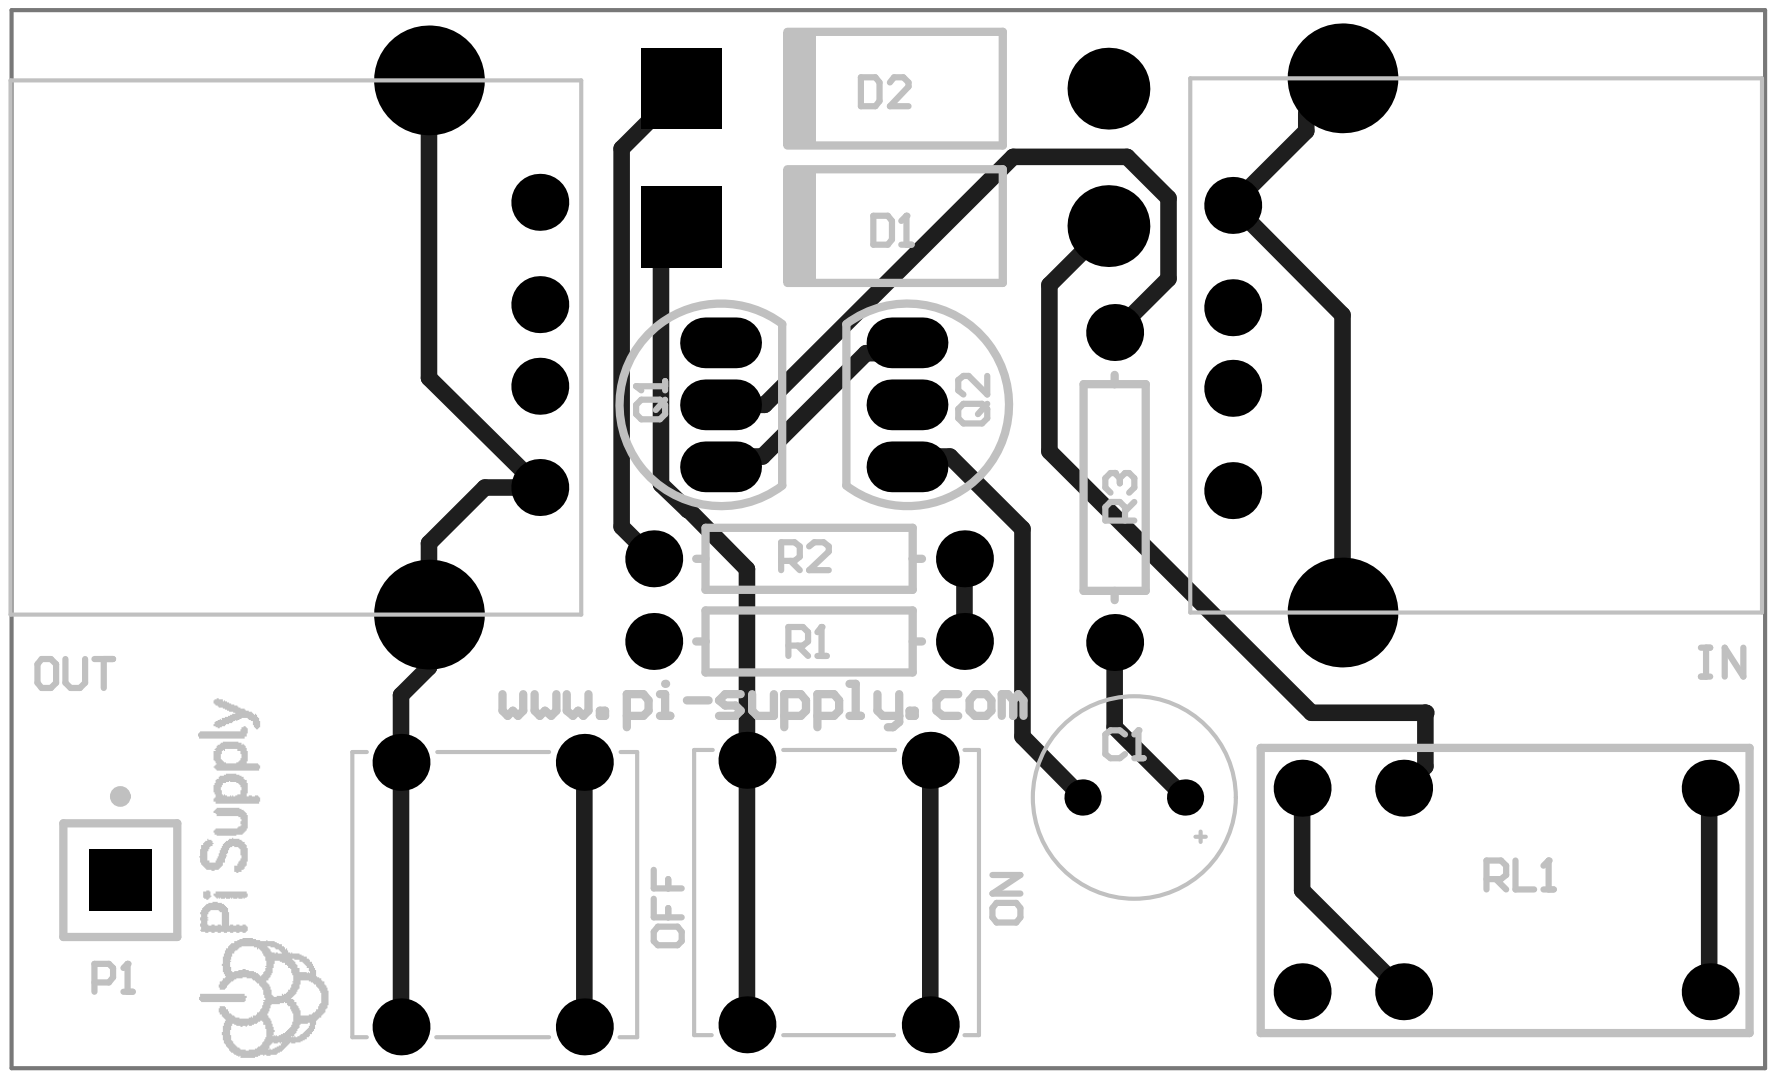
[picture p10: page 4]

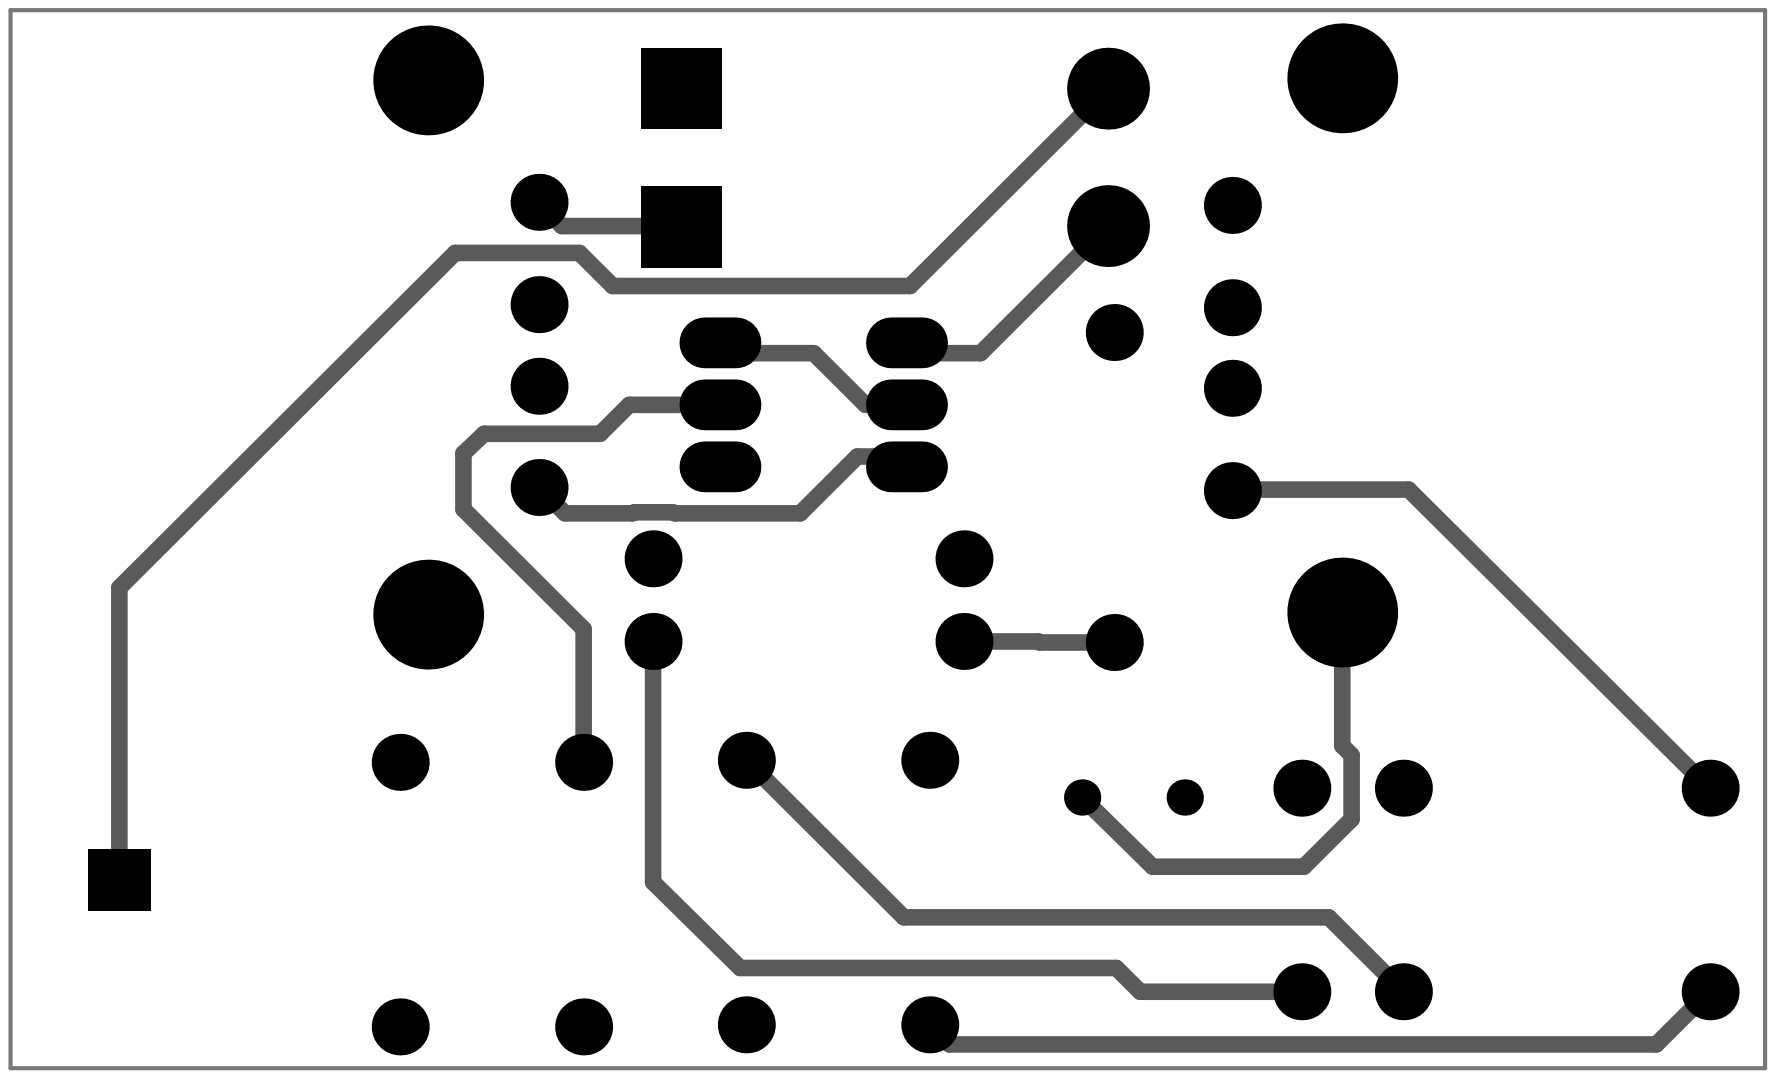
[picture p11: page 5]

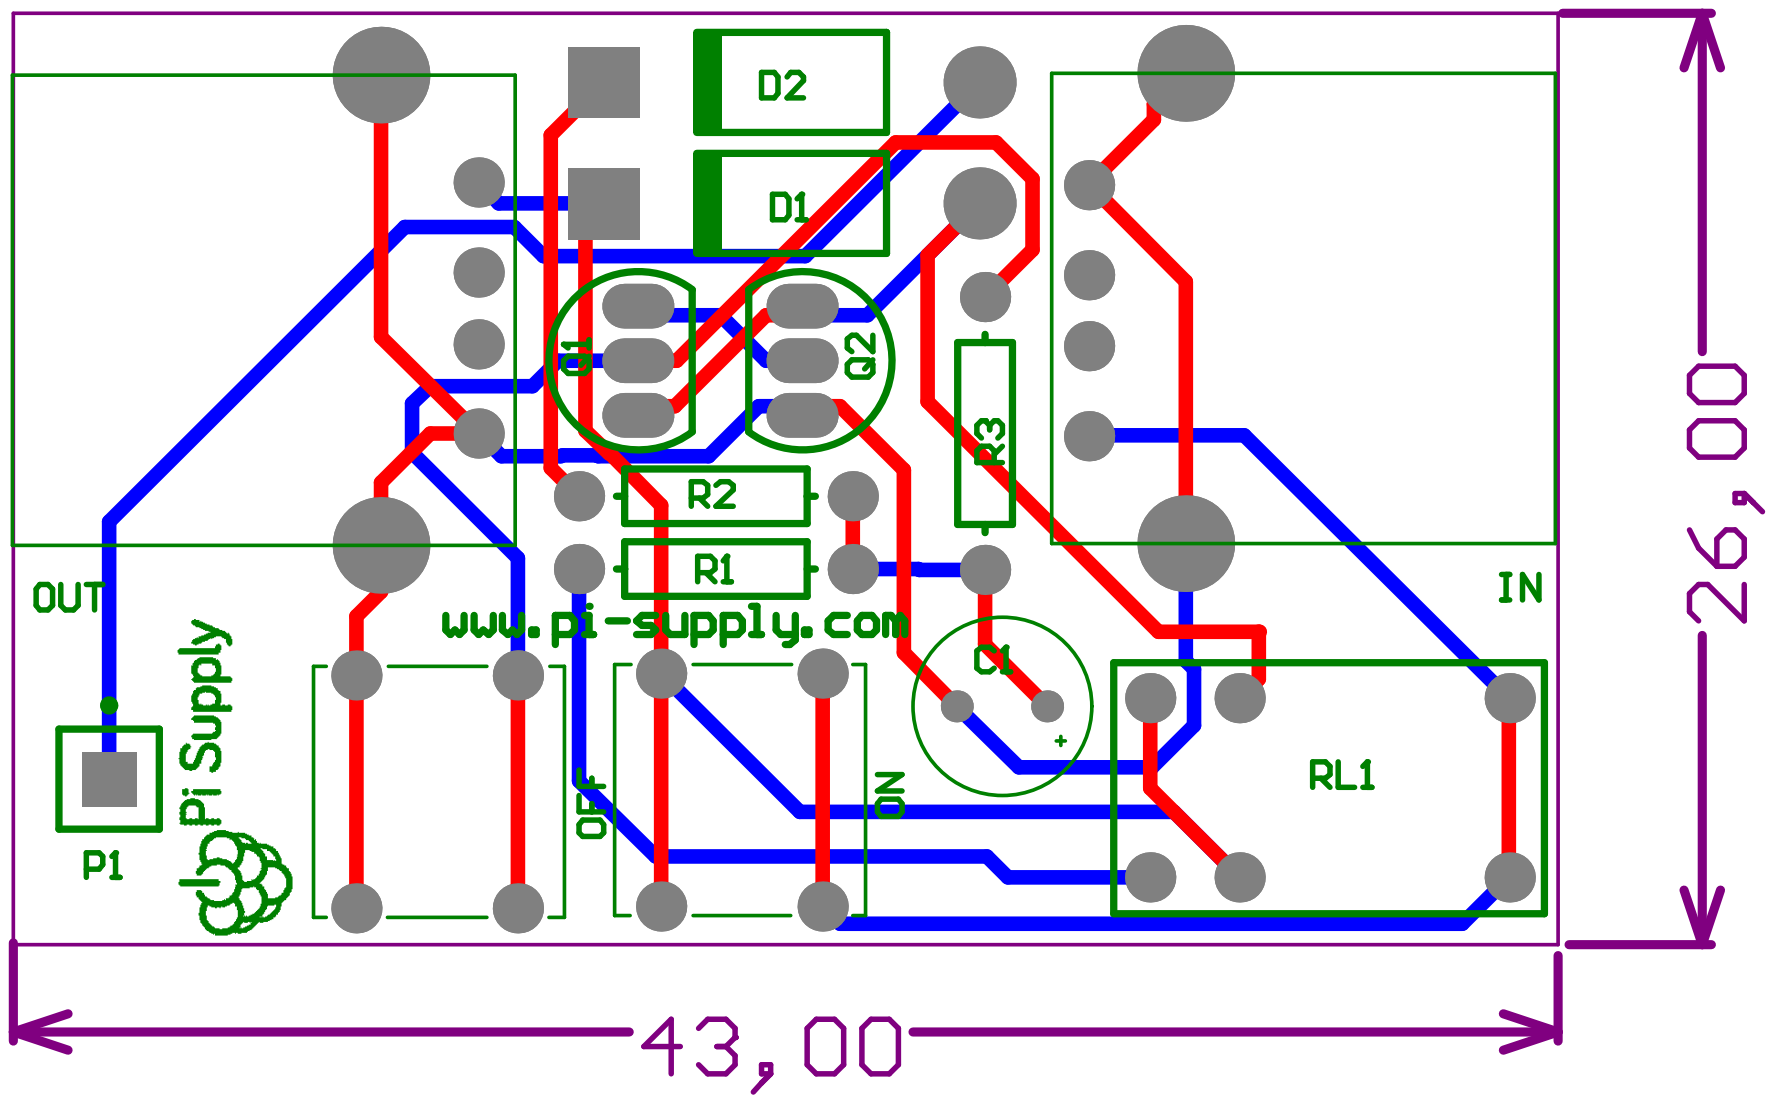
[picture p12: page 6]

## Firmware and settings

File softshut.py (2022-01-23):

#!/usr/bin/env python3

# Import the modules to send commands to the system and access GPIO pins
from subprocess import call
import RPi.GPIO as GPIO
from time import sleep

# Map pin seven and eight on the Pi Switch PCB to chosen pins on the Raspberry Pi header
# The PCB numbering is a legacy with the original design of the board
PinSeven = 7
PinEight = 11
GPIO.setmode(GPIO.BOARD) # Set pin numbering to board numbering
GPIO.setup(PinSeven, GPIO.IN) # Set up PinSeven as an input
GPIO.setup(PinEight, GPIO.OUT, initial=1) # Setup PinEight as output

while (GPIO.input(PinSeven) == False): # While button not pressed
 GPIO.wait_for_edge(PinSeven, GPIO.RISING) # Wait for a rising edge on PinSeven
 sleep(0.1); # Sleep 100ms to avoid triggering a shutdown when a spike occured
 
sleep(2); # Sleep 2s to distinguish a long press from a short press

if (GPIO.input(PinSeven) == False):
 GPIO.output(PinEight,0) # Bring down PinEight so that the capacitor can discharge and remove power to the Pi
 call('poweroff', shell=False) # Initiate OS Poweroff
else:
 call('reboot', shell=False) # Initiate OS Reboot

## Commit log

2017-01-15 Added debounce code to avoid unexpected shutdowns
    [softshut.py]
2017-01-15 Update softshut.py
    Added a reboot functionality
    [softshut.py]
2017-05-10 Added recommendation
    Reminder to install the code before connecting the Switch
2017-11-21 add gerber and schematic files
    add gerber and schematic files
    [PCB1.DRL, PCB1.GBL, PCB1.GBO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]
